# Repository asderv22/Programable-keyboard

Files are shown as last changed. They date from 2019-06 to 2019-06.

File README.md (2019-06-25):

# 自定义宏键盘 Programable-keyboard

这是一个4x4的全键自定义宏键盘 
----
This is a 4x4 full-key custom macro keyboard
----
Engish vision in part 2
----
<br>

可实现功能
----
如上文所述 这是一个16键的自定义宏键盘<br>
每个按键最大实现42行宏定义<br>
以及带有一个滚轮 两个方向模拟了两个不同按键 同样支持最大42行宏定义<br>

使用材料
----
主控板 x1 <br>
~~本来想用arduino实现的 但是我发现了这个好东西~~ <br>
https://item.taobao.com/item.htm?spm=a1z10.1-c.w4004-15650377400.5.524dda783n9xmD&id=548316293212  <br>
这是使用的键盘主控 带有上位机 不需要改代码就能编辑宏  <br>
MX键轴 x16 <br>
键帽 x16 <br>
定制pcb x1 设计文件和Gerber文件在files里 <br>

可选部分
----
这是提供滚轮功能的材料 <br>
不影响键盘部分工作 因此作为可选材料 <br>
机械式编码器 x1 <br>
**光电式当然更好 不过我提供的源码是针对机械式编码器的** <br>
arduino promini x1 <br>
**任何arduino都能工作 这里由于体积限制使用了promini** <br>
1kΩ 贴片电阻 封装0603 x6 <br>
9013 贴片三极管 封装sot-23 x3 <br>
**这两个部分是为了配合arduino实现短接主控板C/R控制脚 具体原理图在files/encoder/encoder.pdf**<br>
**代码在flies/encoder/encoder.ino**<br>

外观&安装
----
外壳采用3d打印方式加工 <br>
键帽我使用的是无刻键帽 再用pet贴纸打印图标黏贴在上面 <br>
经过最近的使用 牢固度挺好 不易掉色 是可选的键帽标识方案 <br>
由于主控板原因 没有再更换usb接口 ~~懒~~ 因此使用了miniusb接口~~2019年了~~ <br>
**外壳的usb开口根据miniusb尺寸设计 更换typec接口请确认尺寸是否正确** <br>

关于文件的重要解释
----
电路原理图在files里 展示为pdf文件 <br> 
原理图通过lceda绘制 .json文件是lceda源码 <br> 
**提供altiumdesigner文件 但不保证完整性与正确性** <br>
<br>
pcb源码展示为files/pcb/keyboard.json<br>
可导入lceda编辑 <br>
**pcb制造Gerber文件展示在files/pcb/Gerber_keyboard.zip** <br>
**使用lceda绘制 生产前请使用Gerber浏览器检查要求** <br>
**提供alitumdesigner文件 由lceda导出 展示为files/pcb/keyboard.pcbdoc** <br>
**由于是导出文件 不确保准确性与可用性 具体参考lceda对于导出文件的解释** <br>
https://docs.lceda.cn/cn/Export/Export-Altium/index.html <br>
<br>
**打印件使用Sketchup绘制并输出stl** <br>
**由于Sketchup特殊的实体密封 不保证所有切片软件&上位机不出错** <br>
**打印前请检查切片结果** <br>

# English vision

Functions
----
as its described, this is a 16-key custom macro keyboard<br>
with maximum 42-line macro definition per key <br>
and a wheel which can simulate two different keys, also support 42-line macro per key <br>

Materials used
----
controllerboard x1
~~I supposed to use an arduino,but later I found some excellent stuff for this project~~<br>
This is the link of the controller which is used in this project <br>
https://item.taobao.com/item.htm?spm=a1z10.1-c.w4004-15650377400.5.524dda783n9xmD&id=548316293212 <br>
*Unfortunately,I didn't find anything similiar to this on aliexpress/ebay*  <br>
MX switches x16 <br>
keycap x16 <br>
custom pcb x1 **the design files and Gerber files are shown in the flies/pcb  floder** <br>

Optional part
----
this is the part which provides the wheel<br>
it doesn't affect the normal function of the keyboard <br>
<br>
mechanical encoder x1 <br>
**photoelectric encoders are clearly better,but the sourcecode I provided is designed for a mechanical encoder**<br>
arduino pro mini x1 <br>
**any arduino should work,I used promini here due to voulme limitation** <br>
1kΩ surface-mount resistor **package 0603** x6   <br>
9013 surface-mount triode **package sot-23** x3 <br>
**this two components are usde to *short* the C/R pins on the controller with arduino**<br>
**specific diagram are shown in the files/encoder/encoder.pdf** <br>
**code is shown as files/encoder/encoder.ino**<br>

Appearance & installation
----
The case is 3d printed<br>
I used none-marking keycap and then paste the icon with PET stickers <br>
it seems to work well,and not faded during the recent use<br>
due to the controller board,the usb interface is still a mini-usb<br>
and the case was designed to fit the mini-usb controller<br>
please check the size if you swap the interface to a typec connector <br>

Important explainations of the files
----
the circuit diagrams are shown as .pdf files in the\files folder <br>
diagrams are drew using LCEDA **also known as easyeda worldwide** <br>
the .json files are LCEDA source codes which allows import and reedit <br>
<br>
the PCB is created via lceda<br>
sourcecodes are shown as files/pcb/keyboard.json <br>
also allows import and reedit <br>
**PCB Gerber files are shown as files/pcb/Gerber_keyboard.zip** <br>
**its created via lceda， please check with Gerber broswer before production**<br>
**Alitumdesigner files are provided, shown as files/pcb/keyboard.pcbdoc**<br>
**but they are exported by lceda,so the accuracy is unknown** <br>
**for more information,see the link below about lceda's exported files**<br>
https://docs.lceda.cn/en/Export/Export-Altium/index.html<br>
<br>
the 3d print .stl files are created via Sketchup <br>
due to the special solid sealing of Sketchup <br>
there might be small problems while using different slicing softwares (it works fine with cura) <br>
double check your slicing software before print <br>

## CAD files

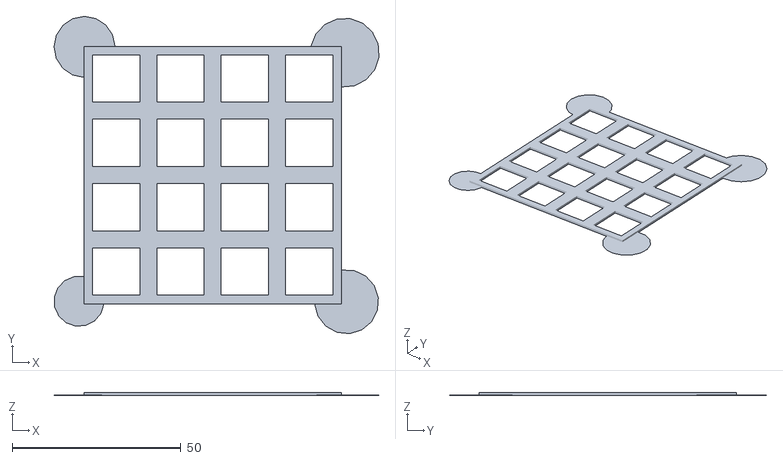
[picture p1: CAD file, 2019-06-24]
3d/locateboard.stl
96.2 x 93.9 x 1.00

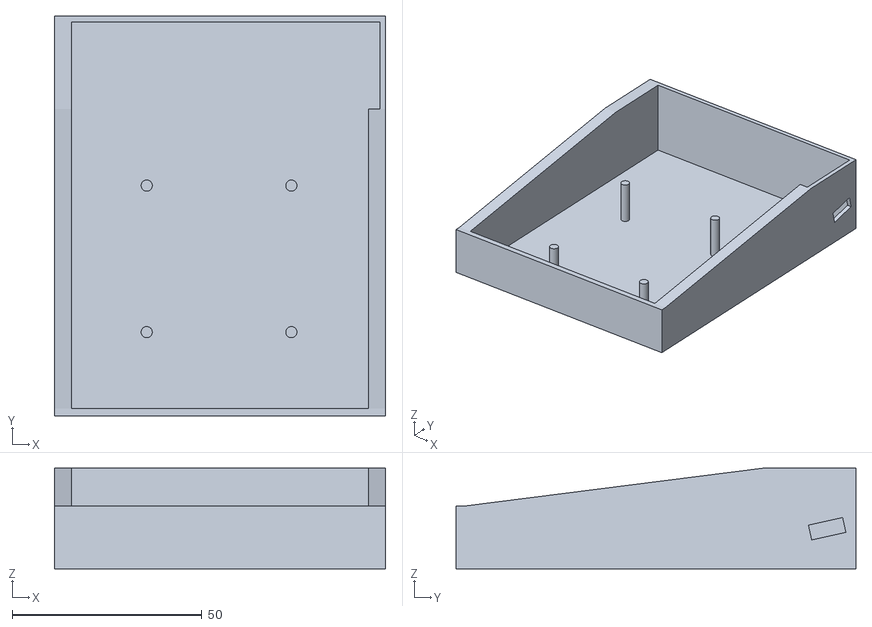
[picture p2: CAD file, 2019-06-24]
3d/bottomcase.stl
87.2 x 105.3 x 26.5

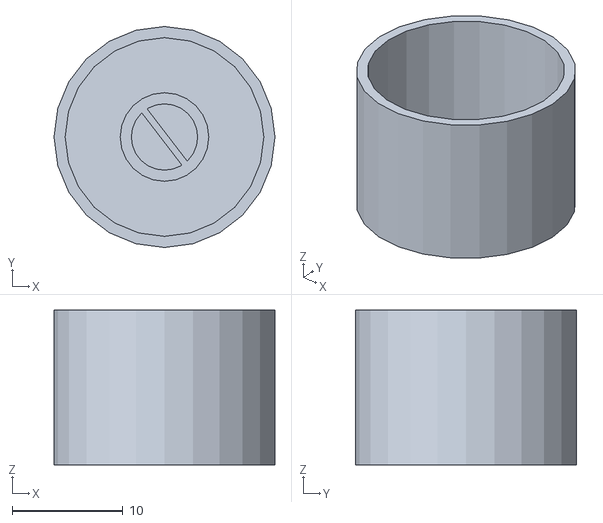
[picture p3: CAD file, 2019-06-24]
3d/wheel.stl
20.0 x 20.0 x 14.0

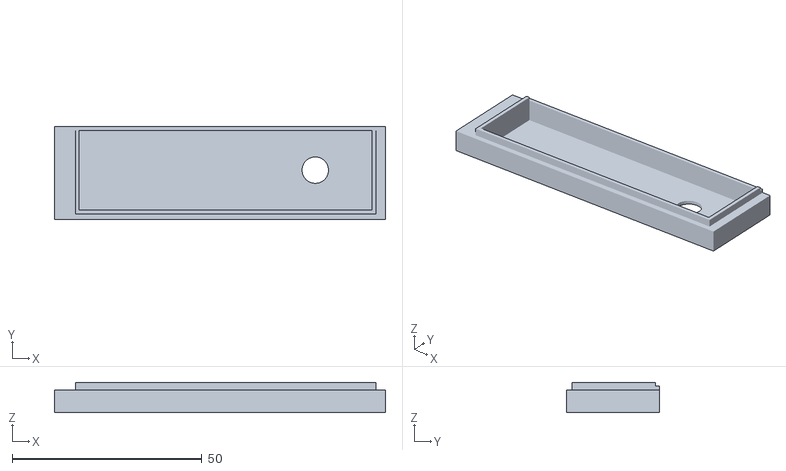
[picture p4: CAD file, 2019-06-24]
3d/topcover.stl
87.2 x 24.5 x 8.00

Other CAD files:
3d/bottomcace.skp
3d/locateboard.skp
3d/topcover.skp
3d/wheel.skp

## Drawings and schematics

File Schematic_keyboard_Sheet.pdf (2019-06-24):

## From Arduino BUS C

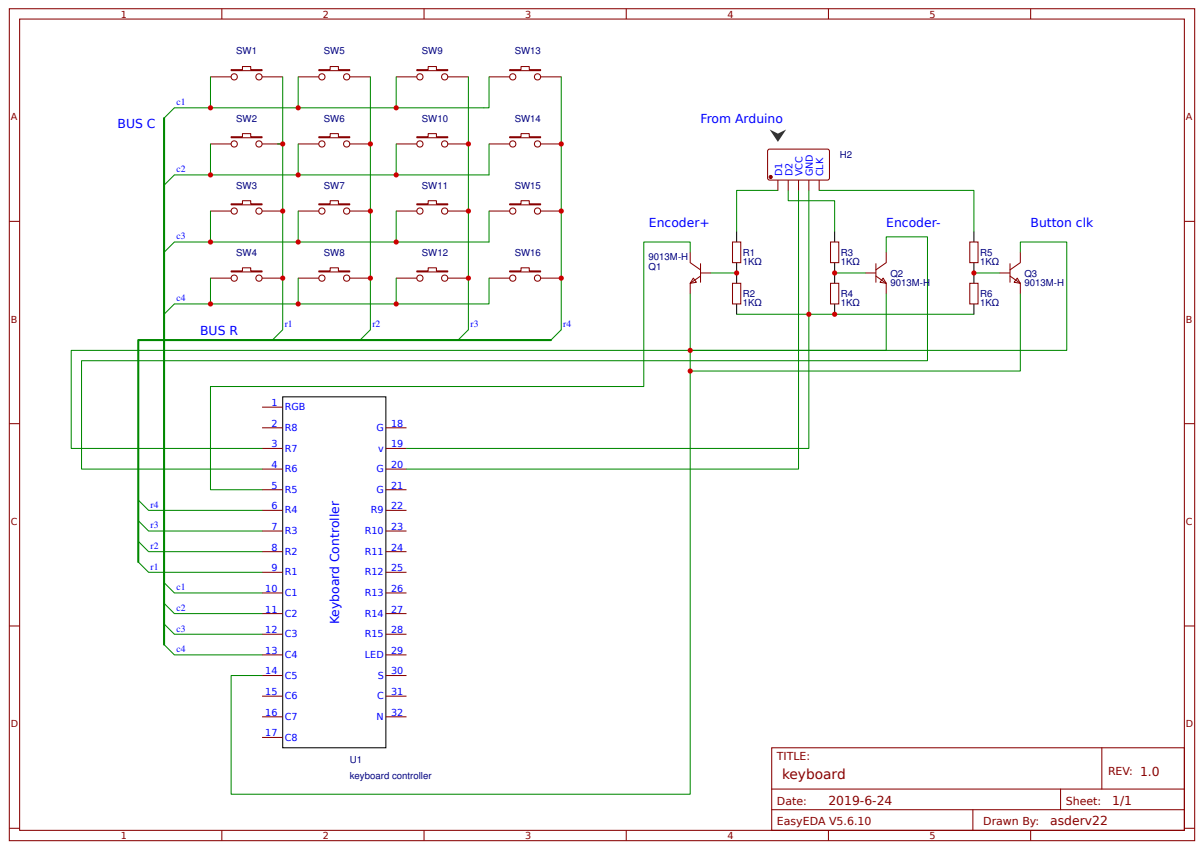
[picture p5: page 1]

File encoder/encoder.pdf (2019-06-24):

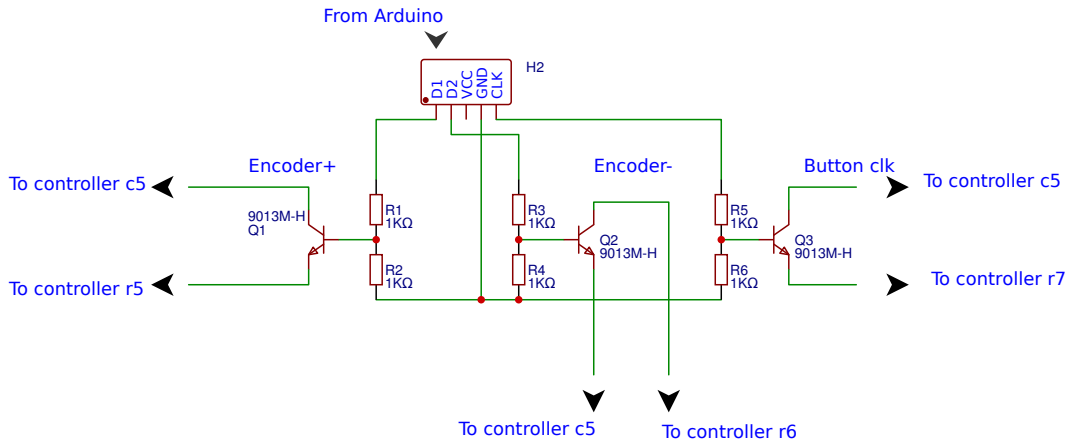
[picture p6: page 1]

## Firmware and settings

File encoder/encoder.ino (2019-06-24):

#define ENCODER_A_PIN 2  //编码器A针
#define ENCODER_B_PIN 3  //编码器B针
#define SWITCH_PIN    4  //编码器按键
#define KEY_VOLUP     5  //主控音量加
#define KEY_VOLDN     6  //主控音量减
#define KEY_PRE       7  
int val = 1;             //val储存按钮的状态；
int old_val = 1;         //暂存val变量的上一个时间单位；
int old_A = 1;
int old_B = 1;
int state = 0;          
int now_A;
int now_B;
int now_A_check;

void setup() {           
  pinMode(ENCODER_A_PIN, INPUT);    
  pinMode(ENCODER_B_PIN, INPUT);    
  pinMode(SWITCH_PIN, INPUT);  
  pinMode(5,OUTPUT);
  pinMode(6,OUTPUT);
  pinMode(7,OUTPUT);
  
  attachInterrupt(0, read_PIN2_change, CHANGE);  //在UNO中，中断口0是指Pin2；中间的中断函数译‘读取跳变’；CHANGE触发是指电平交替变换；
  //外部中断说明：attachInterrupt(interrupt, function, mode);//interrupt为你中断通道编号，function为中断函数，mode为中断触发模式；

  digitalWrite(KEY_VOLUP,LOW);
  digitalWrite(KEY_VOLDN,LOW);
   digitalWrite(KEY_PRE,LOW);
}

void loop()
{                                        //循环程序开始，读取两次为防止误触发，读取成功后才在串口打印出来；
  val = digitalRead(SWITCH_PIN);       //读取按钮信息，平时是高电平，不按下时，都是高电平；
  old_A = digitalRead(ENCODER_A_PIN);  //读取空闲状态下的编码器A针数值；
  old_B = digitalRead(ENCODER_B_PIN);  //读取空闲状态下的编码器B针数值；

  if (val == LOW)
  {                                      //读取SWITCH_PIN脚值，如果等于LOW，则延迟10毫秒；
    delay(10);
    if ((val == LOW) && (old_val == HIGH))
    {                                      //读取SWITCH_PIN脚值，如果两次确认后等于LOW，则
      state = 1 - state;
    }
  }
 
  old_val = val;         //重要：old_val的值赋值成现时val的值，告诉程序‘按键已被按下一次’，如果按钮不释放再按下，LED状态不会被改变；

  if (state == 1)                                   //LED变量 状态判断，然后决定是否点亮LED灯；
  { digitalWrite(KEY_PRE,HIGH); //给三极管1基级导通信号 控制短接主控c1 r1
    delay(500);
    digitalWrite(KEY_PRE,LOW);
  }
  else {
   digitalWrite(KEY_PRE,LOW);
  }
}

void read_PIN2_change()  //编码器旋转检测函数
{
  now_A = 1 - old_A;
  now_B = digitalRead(ENCODER_B_PIN);
  now_A_check = digitalRead(ENCODER_A_PIN);
 

  if ((old_B == now_B) && (old_A == old_B) && (old_A != now_A) && (now_A_check == now_A))
  { Serial.println("ENCODER -");
    digitalWrite(KEY_VOLDN,HIGH); //给三极管1基级导通信号 控制短接主控c1 r1
    delay(500);
    digitalWrite(KEY_VOLDN,LOW);
  }

  if ((now_A == now_B) && (old_A != now_A) && (now_A_check == now_A))
  { Serial.println("ENCODER +");
  digitalWrite(KEY_VOLUP,HIGH); //给三极管2基级导通信号 控制短接主控c2 r1
    delay(500);
    digitalWrite(KEY_VOLUP,LOW);
  }
  
}
